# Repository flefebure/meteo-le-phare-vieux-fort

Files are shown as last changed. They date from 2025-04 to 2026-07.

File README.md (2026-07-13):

# La balise météo du phare de Vieux-Fort en Guadeloupe

Nous sommes André ("l'électricien"), Yves ("le chef de projet"), Franck ("le data engineer") et Noël (le Potomitan du phare), quatre pratiquants de wingfoil réguliers (pas des plus jeunes) du spot. Vous nous avez sans doute croisés si vous fréquentez le lieu pour naviguer, plonger, sauter, bronzer, pique-niquer... dans cet endroit magnifique.

Avec le support de Thierry pour la partie "électronique", nous sommes à l'origine de l'installation de ce matériel qui a été mis en place avec une approche "DIY" et communautaire.

Vous trouverez ici le processus d'installation de cette borne, afin que vous puissiez la répliquer. Nous vous y encourageons.

## Choix des technologies

### Le matériel

La borne est destinée a être installée sur la galerie au sommet du phare de Vieux-Fort. Ainsi il est primordial qu'elle soit la plus robuste et la plus autonome possible. En effet toute intervention nécessitera une synchronisation avec le personnel des phares & balises. Par ailleurs, la borne ne pourra pas puiser son énergie au niveau des installations électriques du phare, il faut donc qu'elle soit autonome en énergie.

Basiquement, nous devions arbitrer entre 2 technologies :

1. Un montage communiquant sur un réseau haut-débit (GSM 4G/5G)
   * Avantages : Réseau autonome. Transmission des données à haute fréquence. Possibilité d'équiper la borne d'une caméra.
   * Inconvénients : technologie gourmande en énergie. Nécessité de mettre en place une recharge solaire (relativement) conséquente.
2. Un montage communiquant sur un réseau bas-débit (LORA ou SigFOX)
   * Avantages : Très économe en énergie, autonomie théorique de plusieurs années.
   * Inconvénients : Nécessité d'intégrer un point d'accès à Internet. Webcam pas envisageable.

Le point de l'énergie étant prédominant, c'est sur une installation Lora que le choix s'est porté. C'est Yves, qui vit à quelques centaines de mètres à vol d'oiseau qui hébergera la passerelle Internet.

### Le logiciel

Les choix suivants s'offraient a nous :

1. Mettre en place une stack "Internet Of Things" complète avec un broker MQTT et un site web autonome abonné à ce broker et chargé d'exposer les données météo
2. Centraliser le traitement des données au niveau de la gateway Lora et s'appuyer sur un service à la "WindGuru" pour présenter les données.

Par souci de simplicité, c'est l'option 2. qui a été choisie. Néanmoins, afin d'assurer une redondance, la borne sera intégrée à 2 services tiers : WindGuru et OpenWindMap

## Raccordement des matériels

La borne se compose des éléments suivants :

| Item | Lien | Prix | Doc |
| :---: | :---: | :---: | :---: |
| Anémomètre Davis 6410 | [Fiche produit](https://github.com/flefebure/meteo-le-phare-vieux-fort/blob/0f8d7a7ca1cc759bb87fbd7ad5027cff3bb662dc/medias/6410_An%C3%A9mom%C3%A8tre_FICHE%20PRODUIT_FR_DAVIS-1.pdf) | ~245€ | [Manuel](https://www.meteo-shopping.com/fr/capteurs/109-anemometre-girouette-vantage-pro.html) |
| Boitier émetteur Dragino SN50v3-LS | [Fiche produit](https://www.dragino.com/products/lora-lorawan-end-node/item/260-sn50v3-lb-ls.html) | ~60€ | [Manuel](https://wiki-old.dragino.com/xwiki/bin/view/Main/User%20Manual%20for%20LoRaWAN%20End%20Nodes/SN50v3-LB/) |
| Gateway Lora Dragino LPS8v2 | [Fiche produit](https://www.dragino.com/products/lora-lorawan-gateway/item/228-lps8v2.html) | 190 à 260€ suivant model | [Manuel](https://wiki-old.dragino.com/xwiki/bin/view/Main/User%20Manual%20for%20All%20Gateway%20models/HP0C/) |
| Capteur de température DS18B20 | [Fiche produit](https://www.amazon.fr/DS18B20/s?k=DS18B20) | ~3 € | [Datasheet](https://www.analog.com/media/en/technical-documentation/data-sheets/ds18b20.pdf) |
| Divers : Mât etc. | ? | ??€ | ?? |

Le boitier émetteur Dragino SN50v3-LB/LS existe en 2 versions :
*	SN50v3-LB qui fonctionne sur pile Li/SOCl2 de 8500mAh d'une durée d’environ 3-5 ans (suivant consommation des capteurs)
*	SN50v3-LS qui fonctionne sur panneau solaire + batterie lithium ion

La version SN50v3-LS a été choisi car elle évite la maintenance d’un changement de batterie.

### Raccordement des éléments

La girouette/anémomètre Davis est câblée avec un connecteur RJ11 male. Le capteur de température est câblé avec une fiche Dupont 3pin male.

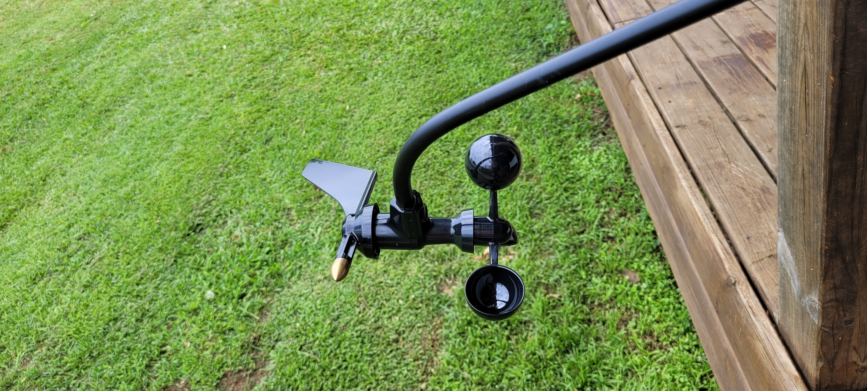
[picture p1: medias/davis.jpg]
girouette/anémomètre Davis

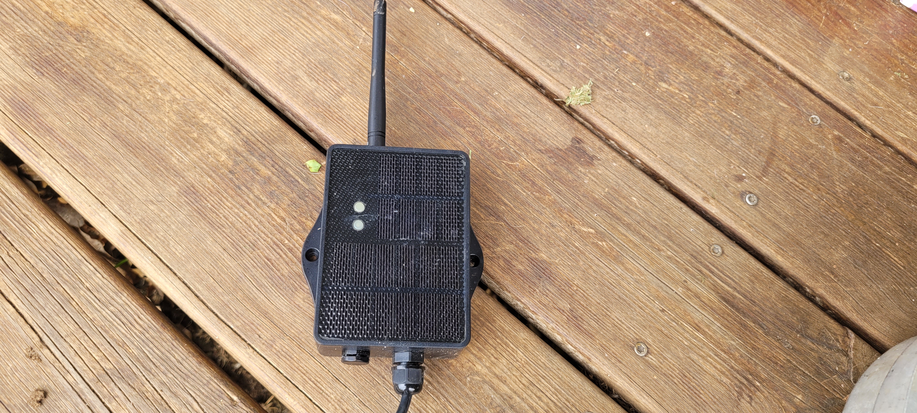
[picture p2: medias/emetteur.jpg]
emetteur Dragino

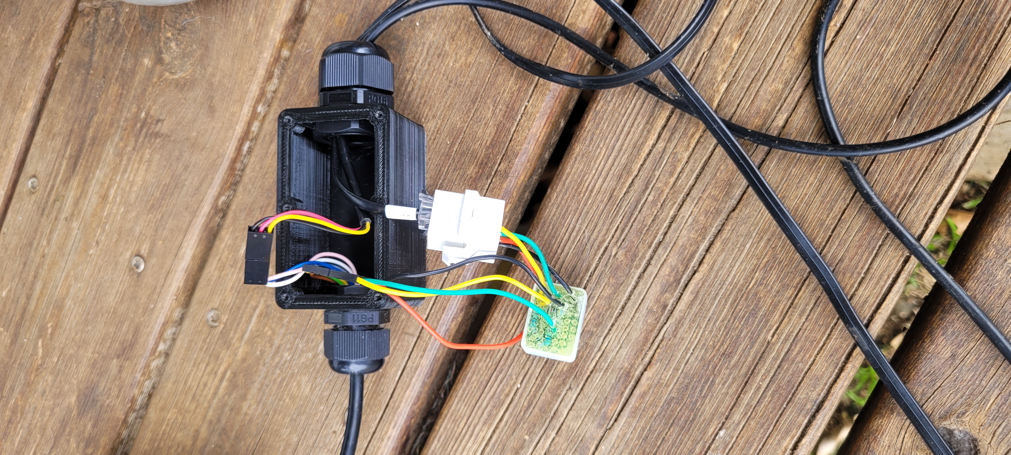
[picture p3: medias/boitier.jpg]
Cablage et boitier imprimé en 3D


La tension de sortie de la girouette varie entre 0V et la tension d'alimentation du boitier émetteur Vdd soit 3.3V. La tension d'entrée du convertisseur ADC de l'émetteur doit être comprise entre 0.1V et 1.1V. Il faut donc mettre en œuvre un pont de résistances afin d'adapter le voltage

Principe :

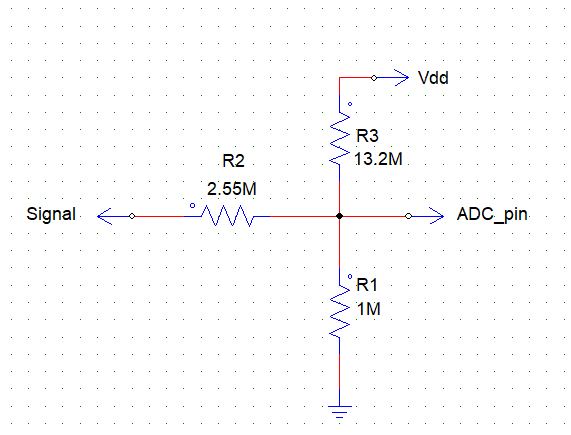
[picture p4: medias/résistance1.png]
Adaptation du voltage


Schema de branchement :

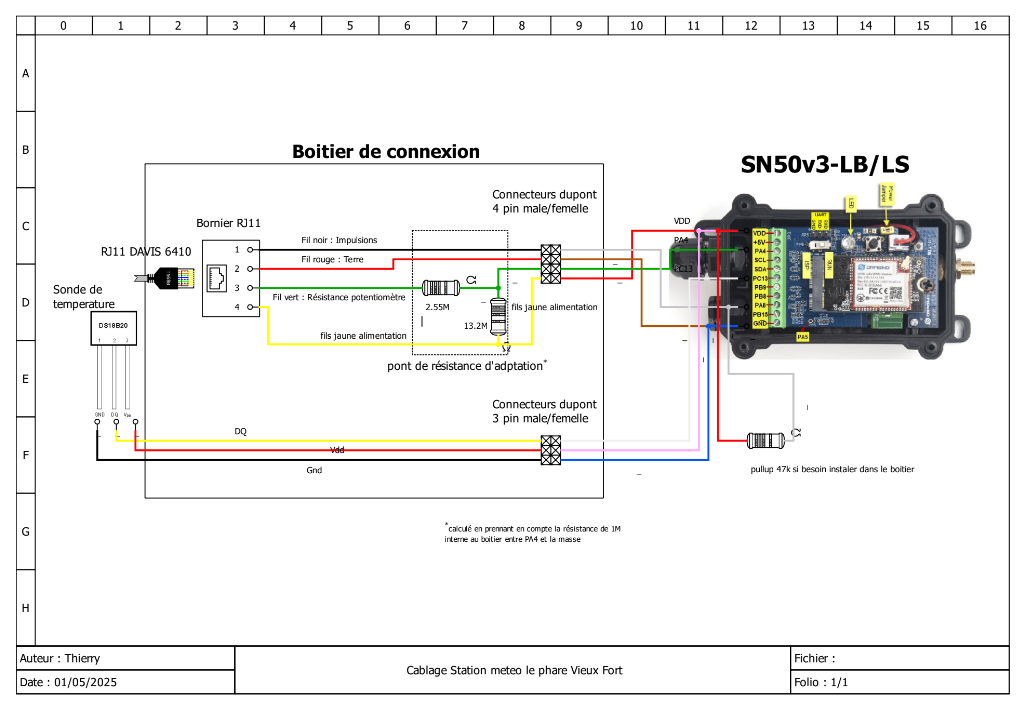
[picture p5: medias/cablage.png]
Schema de branchement


NB:

* Le circuit des résistances est pris dans de la résine coulée dans un petit boitier
* L'ensemble des connections est contenu dans un boitier imprimé en 3D avec du PETG comportant 2 passe-câble avec presse-étoupes en plastique étanche PG11 et PG13.5. Les presse-étoupes ont un diamètre interne de 11 mm et 13.5 mm pour pouvoir insérer les câbles avec leur connecteur. Enfin des bagues d’étanchéité sont imprimée en TPU pour adapter le diamètre des câbles au presse étoupe. Les différent fichiers STL sont disponible ci-dessous :
  * [Bague étanche diamètre 10](medias/bague%20etanche%20d10.5_d5mm.stl)
  * [Bague étanche diamètre 13](medias/bague%20etanche%20d13.5_d4mm.stl)
  * [Haut du boitier](medias/boitier%20connexion%20haut.stl)
  * [Bas du boitier](medias/boitier%20connexion%20bas.stl)

La sonde de température est la classique DS18B20:

 * 
   
 celle-ci est installé dans un écran radiatif qui est une adaptation/mise à l'échelle de [Radiation Shield For Weather Station Temperature/Humidity](https://www.thingiverse.com/thing:1067700):
 
  

L'écran radiatif est imprimé en PETG blanc. Les différents fichiers STL sont disponible ci-dessous :
  * [Support écran](medias/Rad_Shd_Vert_mount_60%25.stl)
  * [porte sonde](medias/Rad_Shd_Porte_sonde_60%25.stl)
  * [Aillete intermédiare x4](medias/Rad_Shd_ailette_60%25.stl)
  * [Ailette supérieur](medias/Rad_Shd_ailette_superieur_60%25.stl)
  * [écran radiatif complet monté](medias/Rad_Shd_Vert_mount_complet_V3_60%25.stl)

L'ensemble des pieces sont relier/empilé entre elle par 3 vis d3mm*60mm qui se visse dans l'ailette supérieur (tarauder les trous avant montage)

### Paramétrage de l'émetteur

Le boitier émetteur Dragino SN50v3-LB/LS est un boitier multi usage qui demande à être configuré en fonction de l’application et des capteurs qui seront connecté dessus. La documentation propose différent mode : [Mode boitier](https://wiki-old.dragino.com/xwiki/bin/view/Main/User%20Manual%20for%20LoRaWAN%20End%20Nodes/SN50v3-LB/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)

Dans notre cas nous allons utiliser le mode comptage : Mode 6, car nous avons à compter les tours de rotation de l’anémomètre, mesurer le potentiomètre de la girouette et mesurer la température.
Le boitier SN50v3-LB/LS prend en charge les méthodes de configuration suivante :
* Commande AT via connexion Bluetooth (recommandée): [BLE Configure Instruction](https://wiki-old.dragino.com/xwiki/bin/view/Main/BLE%20Bluetooth%20Remote%20Configure/).
* Commande AT via connexion UART voir : [UART Connection](https://wiki-old.dragino.com/xwiki/bin/view/Main/UART%20Access%20for%20LoRa%20ST%20v4%20base%20model/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).
* Par liaison descendante LoRaWAN.  Voir instruction : [IoT LoRaWAN Server section](https://wiki-old.dragino.com/xwiki/bin/view/Main/).

La méthode « Commande AT via connexion Bluetooth » a été utilisé :

Après installation sur un téléphone Android de l'utilitaire dragino "Devices.Toll" les commandes AT nécessaire à la configuration souhaitée ont été envoyé :

* Commande de passage en mode 6 : AT+MOD=6
* Définition de la période de transmission en ms : AT+TDC=30000 (30000ms= 30s)

### Configuration du réseau Lorawann de la passerelle utilisé par l'émetteur

La passerelle permet de configurer l'accés à un réseau Lorawann comme par exemple [The Things Network V3](https://www.thethingsnetwork.org/) ou d'utiliser le réseau lorawan local à la passerelle. Dans notre cas nous avons utilisé le réseau local "Chirpstack". les informations de configuration sont à retrouver dans Manuel utilisateur de la Gateway Lora Dragino LPS8v2 : [Manuel](https://wiki-old.dragino.com/xwiki/bin/view/Main/User%20Manual%20for%20All%20Gateway%20models/HP0C/)

## Mise en œuvre logicielle

### administration passerelle

Une fois la passerelle Lora branchée sur un routeur internet, celui-ci lui affecte une IP DHCP, par exemple 192.168.1.20
Un acces à http://192.168.1.20 permet d'afficher l'interface d'administration de la passerelle
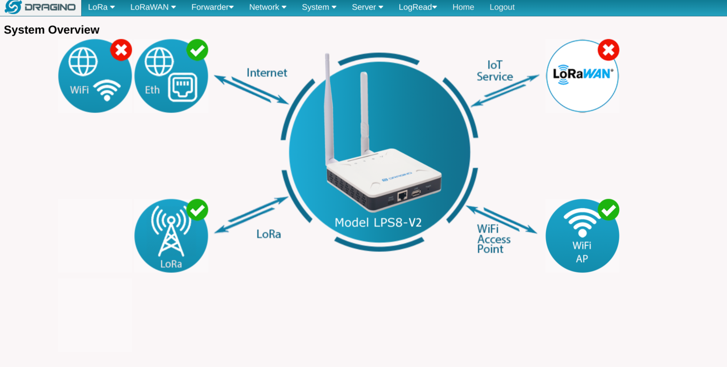
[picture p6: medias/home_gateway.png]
acceuil gateway


Cette interface est surtout utilse pour vérifier que la paserelle est bien connectée à l'émetteur et peut accéder à Internet. La majeure partie des configurations s'effectue via l'utilitaire "Chirpstack" qui est disponible a l'adresse http://192.168.1.20:8080

### Chirpstack

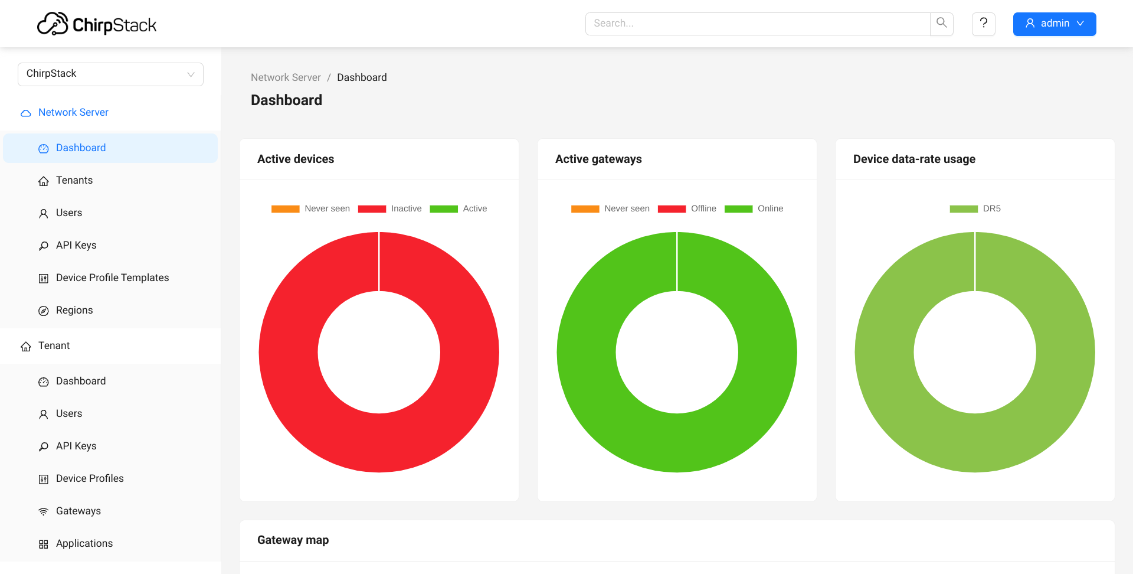
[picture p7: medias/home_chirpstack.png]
acceuil Chirpstack


La premiere tâche est de créer un template pour l'émetteur 
Voici notre configuration :

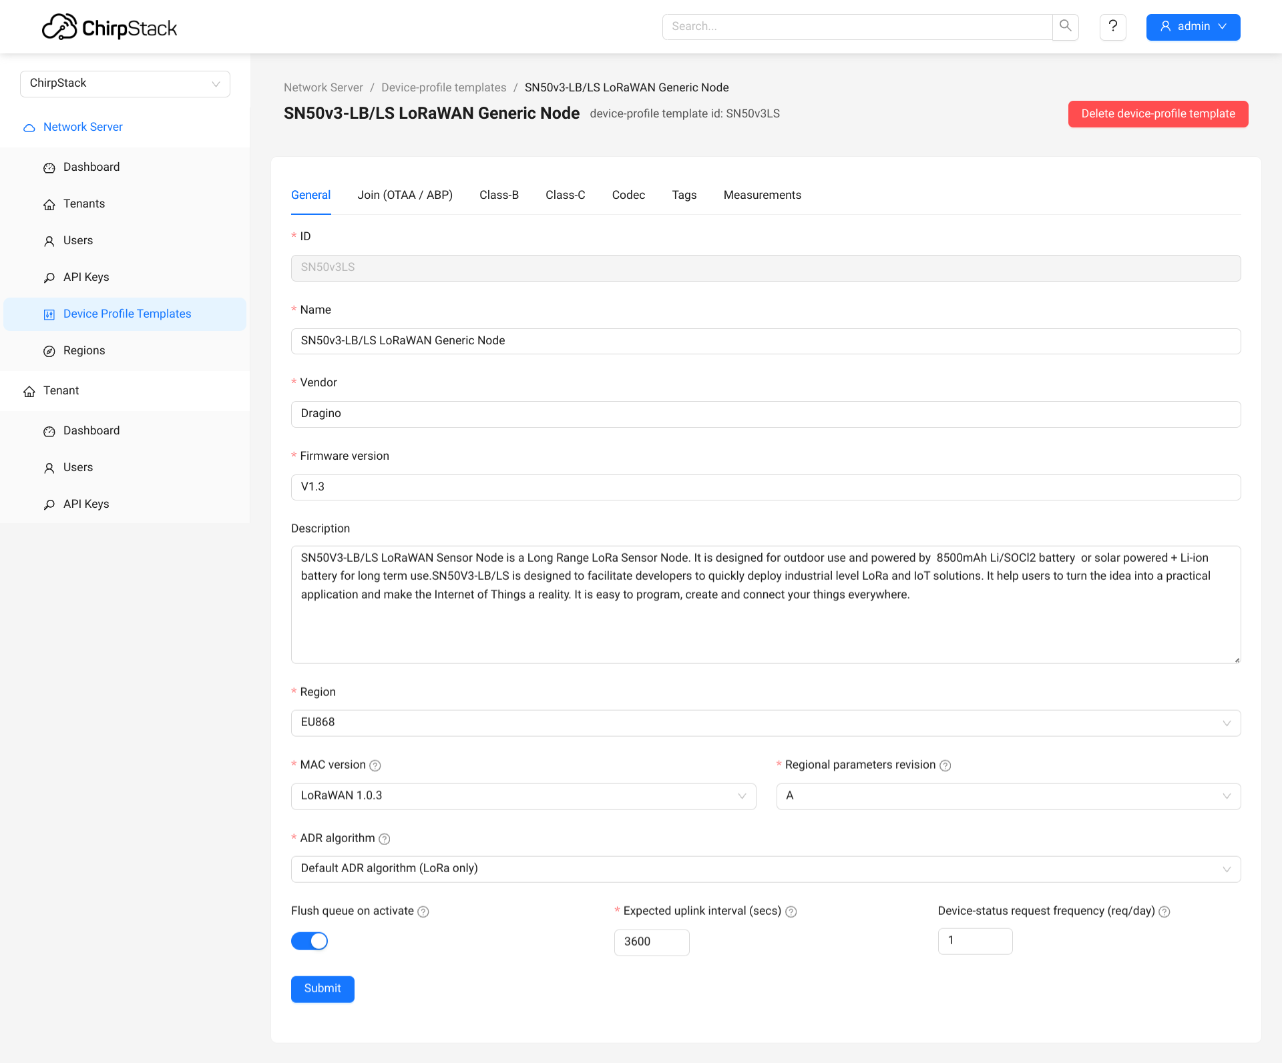
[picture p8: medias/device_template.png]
Template device


Il faut ensuite définir un template, en effet l'émetteur Lora envoie ses données sous forme de trames hexadécimales, le codec va permettre de convertir la charge utile de ces trames en informations utilisables, par exemple la température ou le nombre de rotations de l'anémomètre. 
Le wiki de Dragino vous propose un Codec à utiliser

[Codec](https://github.com/dragino/dragino-end-node-decoder/blob/main/SN50_v3-LB/SN50_v3-LB_ChirpstackV4_decode.txt)

Collez simplement le contenu de ce fichier dans la partie Codec du template

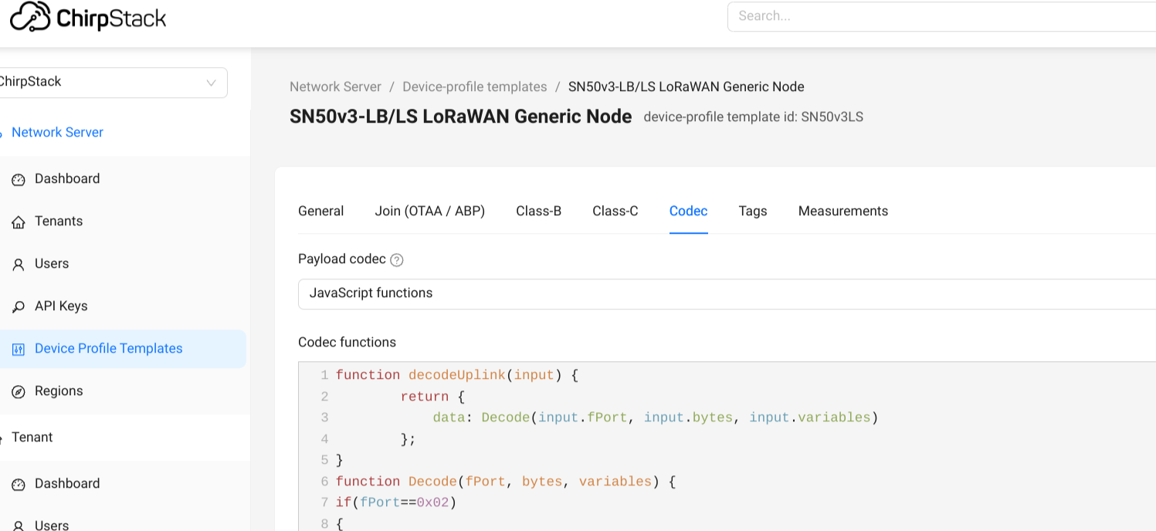
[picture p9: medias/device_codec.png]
Template device


Définissez ensuite une "Gateway". Vous aurez a renseigner le code EUI64 de l'émetteur qui figure sur son étiquette

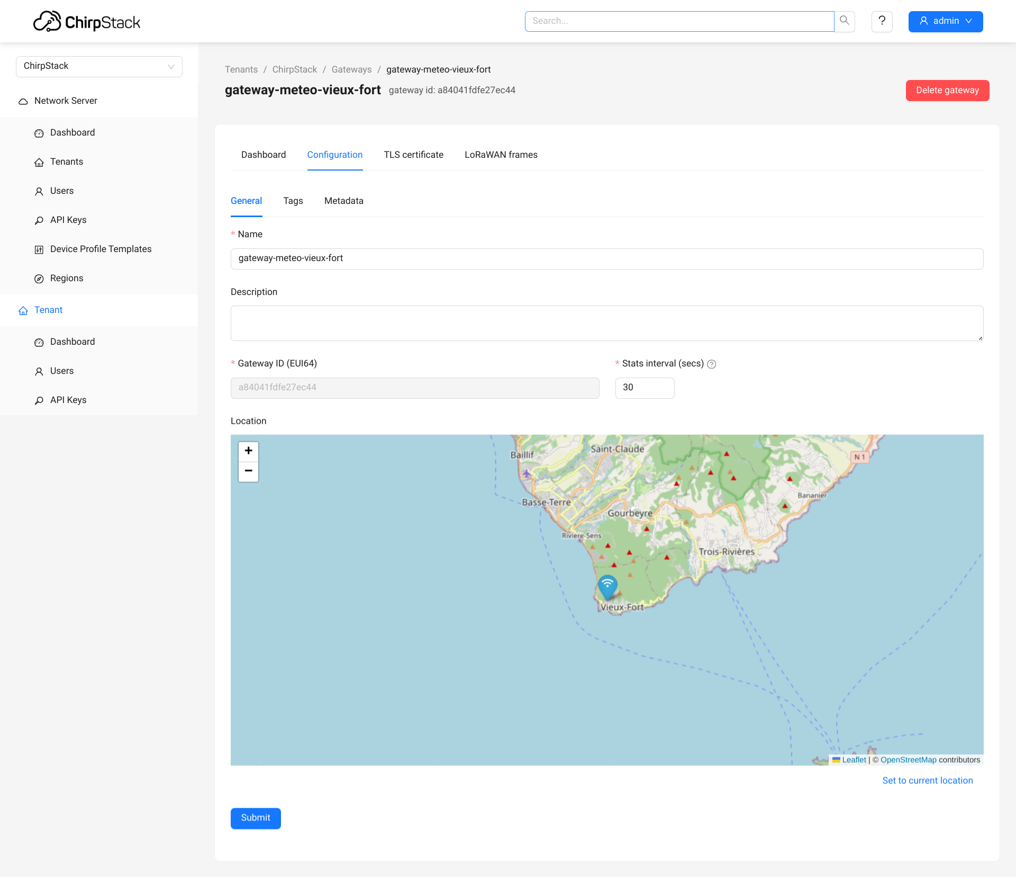
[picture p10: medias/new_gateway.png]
New gateway


Enfin vous aurez a définir une "application", qui fait le lien entre la gateway et le device

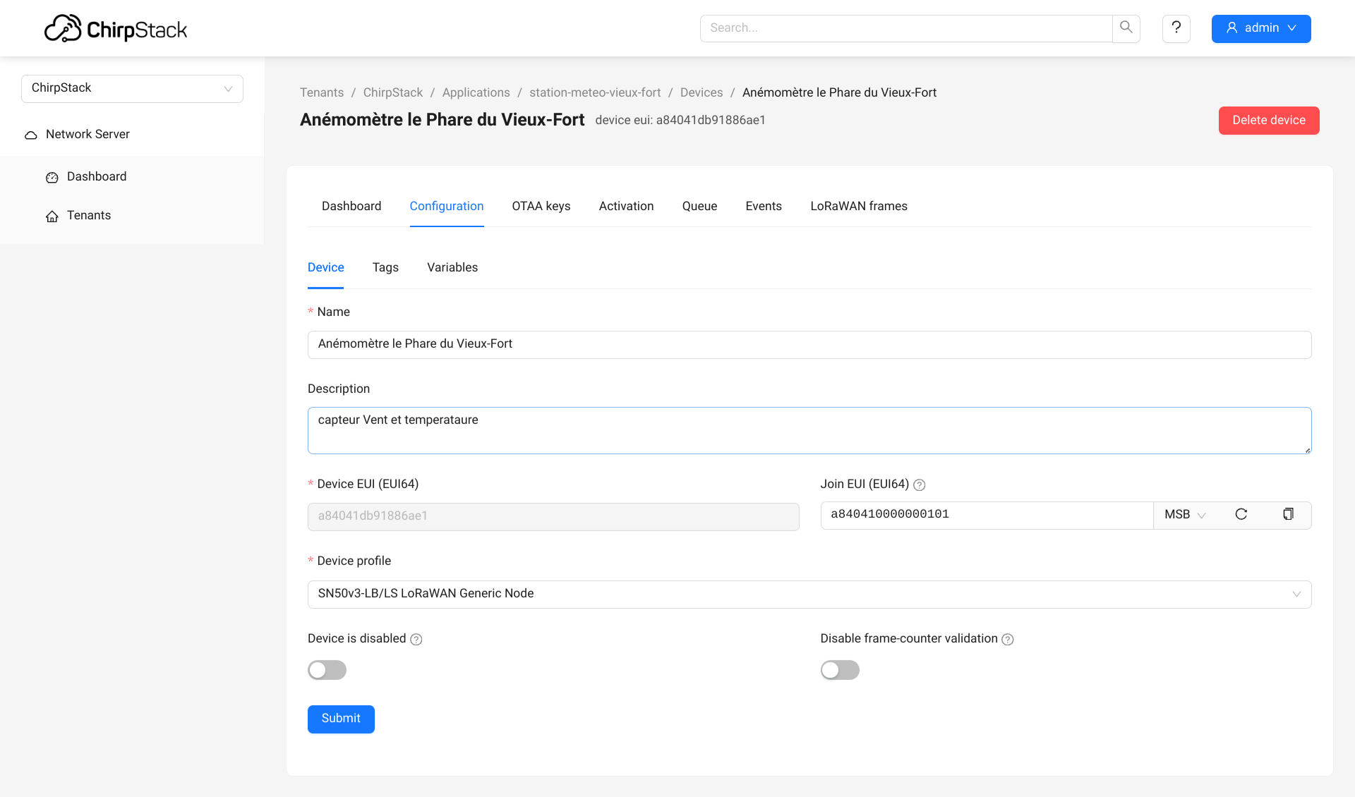
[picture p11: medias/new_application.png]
New app


A ce stade, vous devez pouvoir visualiser les événements décodés qui proviennent de l'émetteur

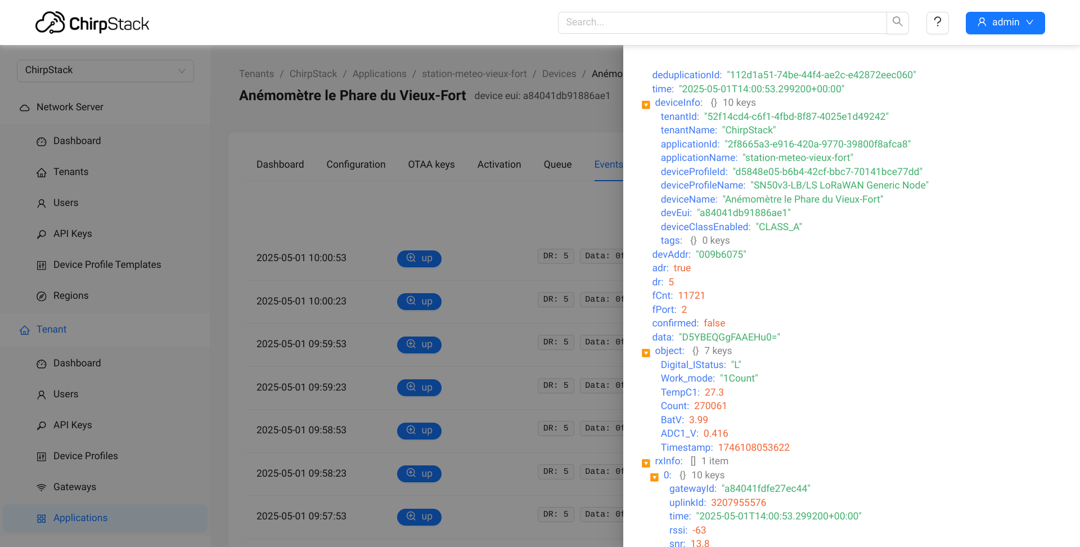
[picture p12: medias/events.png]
Evénements


Pour la suite de la configuration, il était prévu de sauvegarder les événements dans une base locale pour ensuite les traiter et les transmettre aux services tiers (Windguru) et pour cela j'ai essayé de mettre en œuvre une "integration" de type "InfluxDB"

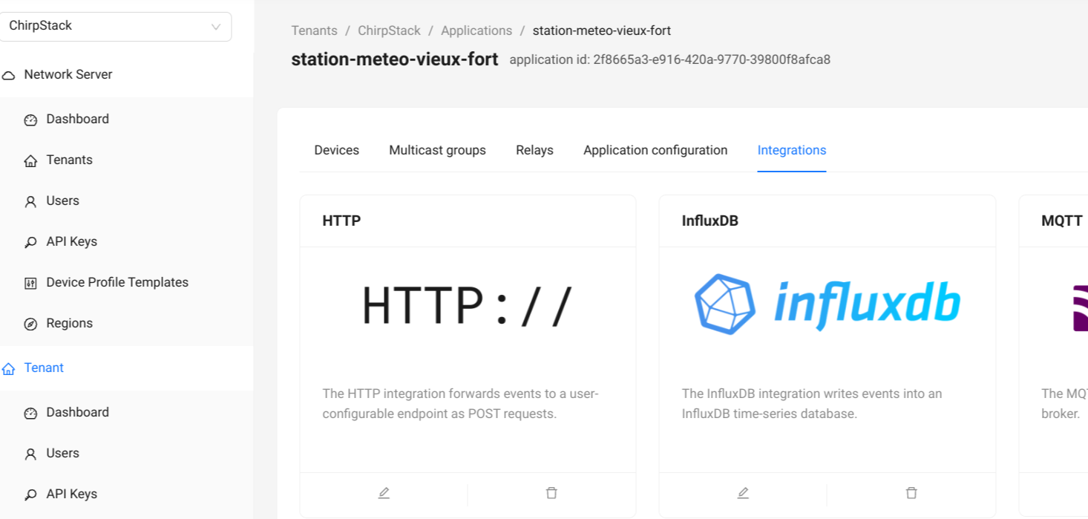
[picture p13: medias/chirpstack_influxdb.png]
Chirpstack to Influx


Néanmoins, je ne suis pas parvenu à faire fonctionner ce connecteur. La mise en œuvre a par la suite été centralisée dans un 3e outil : Node-Red

### InfluxDB

La base conseillée par Dragino n'est pas installée par défaut. Pour l'installer, connectez-vous par SSH a l'IP de la passerelle puis exécutez les commandes suivantes :

```
curl https://repos.influxdata.com/influxdata-archive_compat.key | gpg --dearmor | sudo tee /usr/share/keyrings/influxdb-archive-keyring.gpg >/dev/null
echo "deb [signed-by=/usr/share/keyrings/influxdb-archive-keyring.gpg] https://repos.influxdata.com/debian $(lsb_release -cs) stable" | sudo tee /etc/apt/sources.list.d/influxdb.list
apt update && apt install influxdb
systemclt enable influxdb
systemctl start influxdb
```

Vérifiez ensuite que la base est demarrée avec la commande "systemctl status influxdb"

## Node Red

Node Red est un outil de programmation visuelle (low-code) embarqué dans la passerelle Dragino. Il est disponible à l'adresse http://192.168.1.20:1880

Les mesures des capteurs sont disponibles sur la queue MQTT locale à la passerelle Dragino

Dans RedNode nous allons traiter 2 flux de données :

* Un premier "stream" qui stocke toutes les mesures reçues sur la queue MQTT dans la base InfluxDB
* Un deuxième "stream" qui s'exécute toutes les minutes et qui traite les mesures reçues pendant les 5 dernières minutes afin de les transformer puis de les transmettre a OpenWindMap et WindGuru

Voici comment se présente les 2 streams dans Node Red :

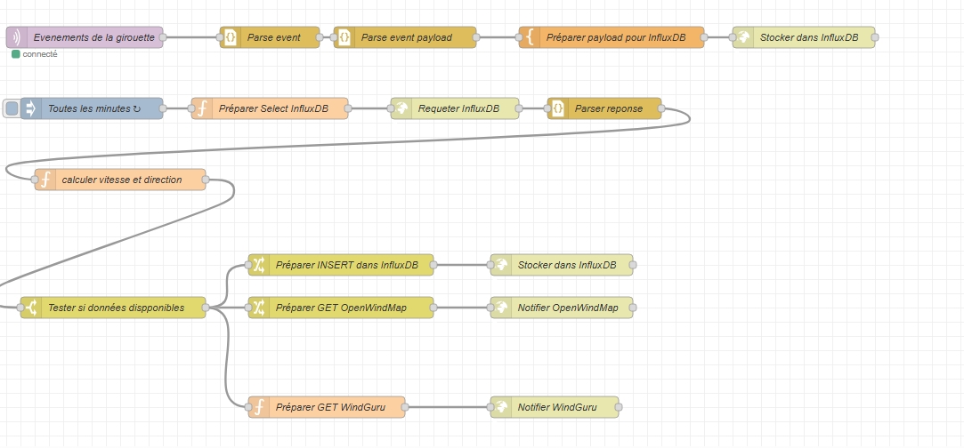
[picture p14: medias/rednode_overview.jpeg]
NodeRed overview


### Stockage des événements

Le flux démarre par un noeud MQTT-IN. Le "topic" est "application/+/device/+/event/+"

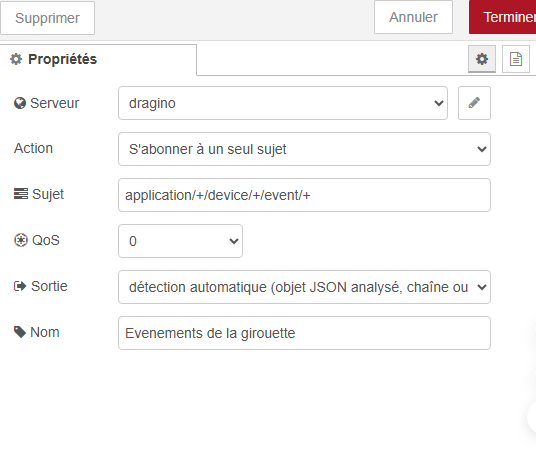
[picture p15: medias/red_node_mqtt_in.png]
MQTT IN


Le format de l'événement est assez particulier. C'est une chaine Json encapsulée dans un autre objet Json. Il faut donc le décoder en 2 étapes. C'est ce qui explique les 2 noeuds "parse event" en cascade

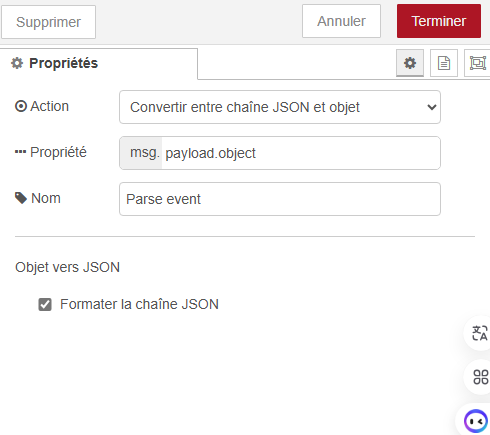
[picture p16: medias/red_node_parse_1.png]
parse event etape 1
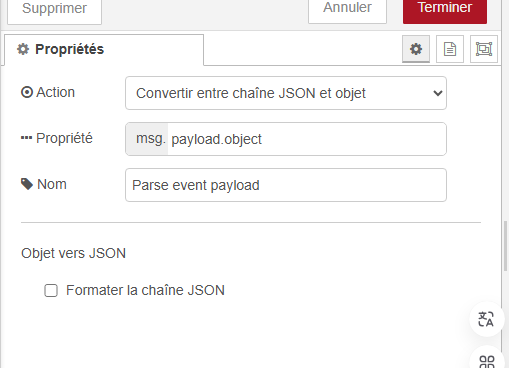
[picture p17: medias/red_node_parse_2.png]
parse event etape 2
  

On prépare alors l'insertion dans InfluxDB, via son API HTTP

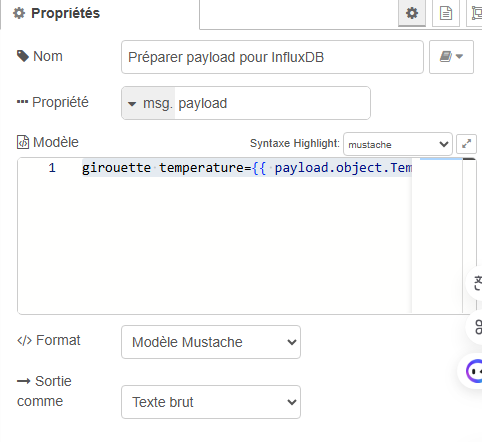
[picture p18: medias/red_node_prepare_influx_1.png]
Prepare Influx insert


```
girouette temperature={{ payload.object.TempC1 }},batterie={{ payload.object.BatV }},rotations={{ payload.object.Count }},voltage={{ payload.object.ADC1_V }} {{ payload.object.Timestamp }}
```

Enfin on insere l'événement dans InfluxDB

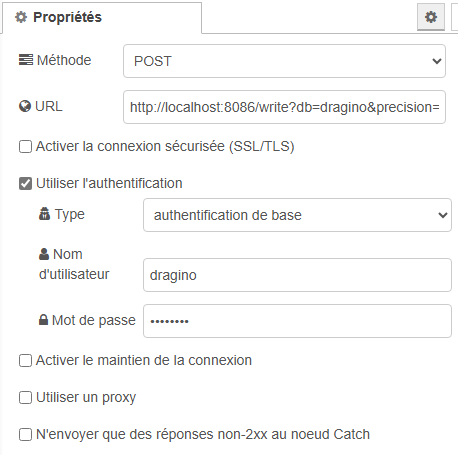
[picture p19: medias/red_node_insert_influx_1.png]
Insertion Influx


### Traitement des événements

Le premier nœud est un scheduler Node Red qui diffuse un événement toutes les minutes.

Nous allons enrichir cet événement avec la liste des mesures recueillies pendant les 5 dernières minutes

TODO : détailler requete et reponse InfluxDB

Les mesures sont disponibles, nous pouvons maintenant calculer les métriques finales selon ces règles :

* Les vitesses en km/h seront données par la formule suivante :  V = P*(2.25*1.60934/T) avec P le nombre de rotations entre 2 points de mesure et T le temps en secondes entre ces 2 mesures (formule adaptée de la documentation DAVIS 6410)
* La vitesse moyenne est obtenue en prenant en compte les 2 points de mesure les plus éloignés sur la période de 5 minutes.
* Les vitesses min et max sont obtenues entre 2 points de mesures consécutifs  (éloignés de 30 secondes) sur la période de 5 minutes.
* La direction du vent en degrés par rapport au nord est donnée par la formule suivante : y = modulo(395,1932806 *x - 59,62030662 + Cal, 360), ou x est la mesure en volts du boitier (entre 0.1 et 1V environ) et Cal est la direction du support girouette par rapport au nord (Si on pointe le support girouette vers le nord alors Cal = 0 si tu pointe l’EST Cal = 90, le sud Cal = 180 et l’ouest  Cal = 270).
la formule donnant la direction du vent en degrés a été obtenue en effectuant une calibration de la girouette connectée au boitier : pour différente position de la girouette on mesure la tension du potentiomètre et la valeur renvoyée par l’ADC du boitier puis on passe une droite de régression a*x+b. si un autre modèle de girouette est  utilisé  ou si un  autre pont de résistance est mis en œuvre, la calibration est à refaire

Le code figurant dans le noeud fonction "calculer vitesse et direction" est donc :

```
var values = msg.payload.results[0].series[0].values
var rotations_reset = 0
var sum_voltage = 0

var payload = {}
payload.min_time = 0
payload.start_rotations = 0
payload.end_rotations = 0
payload.vitesse_min_kmh = 1000000
payload.vitesse_max_kmh = 0

var voltage = 0
payload.count = values.length
msg.payload = payload
if (payload.count < 2)
    return msg;
for (let value of values)  {
    if (payload.min_time == 0) payload.min_time = value[0]
    if (payload.start_rotations == 0) payload.start_rotations = value[3]
    payload.temperature = value[1]
    payload.batterie = value[2]
    sum_voltage = sum_voltage + value[4]
    if (value[3] < payload.end_rotations) 
        rotations_reset = payload.end_rotations
    
    var pulse = value[3] + rotations_reset - payload.end_rotations
    if (payload.max_time > 0) {
        var vitesse_inst_kmh = pulse * 2.25 *  1.60934 * 1000 / (value[0] - payload.max_time)
        if (vitesse_inst_kmh > payload.vitesse_max_kmh)
            payload.vitesse_max_kmh = vitesse_inst_kmh 
        if (vitesse_inst_kmh < payload.vitesse_min_kmh)
            payload.vitesse_min_kmh = vitesse_inst_kmh
    }
    
    payload.end_rotations = value[3] + rotations_reset
    payload.max_time = value[0]
}
// calcul de la direction du vent
var avg_angle = 0
if (payload.count > 0)
    voltage = sum_voltage / payload.count
payload.angle = (395.1932806 * voltage - 59.62030662 + 180) % 360
// calcul de la vitesse
payload.secondes = (payload.max_time - payload.min_time) /1000
payload.pulse = payload.end_rotations - payload.start_rotations
payload.vitesse_kmh = payload.pulse * 2.25 *  1.60934 / payload.secondes 
payload.vitesse_ms = payload.vitesse_kmh / 3.6
payload.vitesse_max_ms = payload.vitesse_max_kmh / 3.6
payload.vitesse_min_ms = payload.vitesse_min_kmh / 3.6
return msg;
```

Un test, utilisant un noeud redNode de type "switch" est mis en place pour arrêter le traitement si on n'a pas trouvé au moins 2 mesures sur la période de 5 minutes

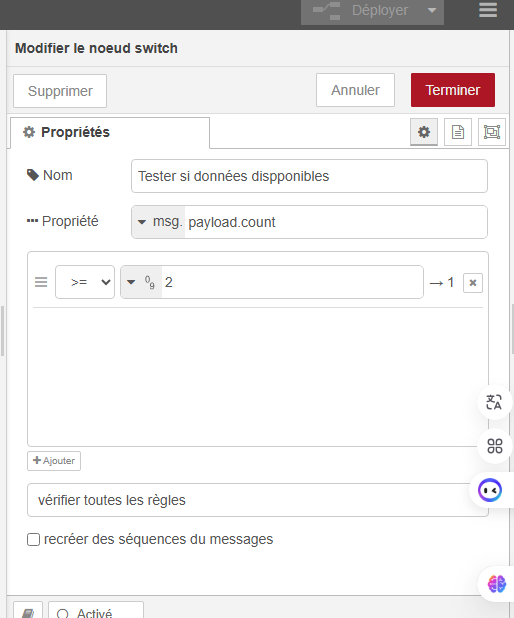
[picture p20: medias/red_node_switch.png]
Test 2 mesures


On prépare l'appel a l'API OpenWindMap

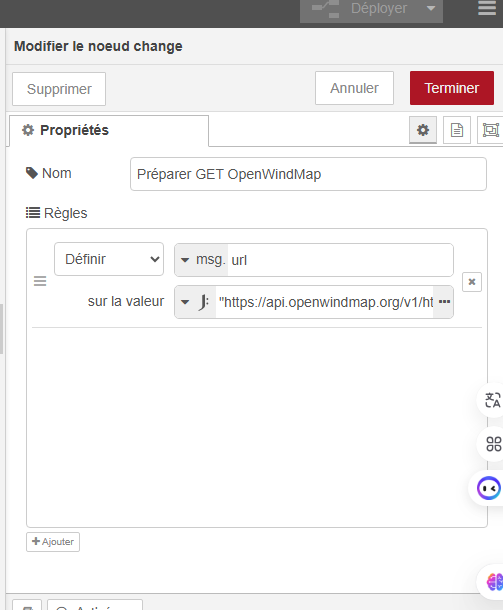
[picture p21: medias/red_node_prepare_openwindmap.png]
prepare openwindmap


```
"https://api.openwindmap.org/v1/http-receive/1227?key=**************&avg=" & payload.vitesse_kmh & "&heading=" & payload.angle & "&voltage=" & payload.batterie & "&temperature=" & payload.temperature & "&date=" & payload.max_time & "&min=" & payload.vitesse_min_kmh & "&max=" & payload.vitesse_max_kmh
```

La préparation de l'appel a l'API Windguru est un peu plus complexe car on doit calculer un MD5. Une fonction autonome permettant de calculer des MD5 est embarquée dans notre code.

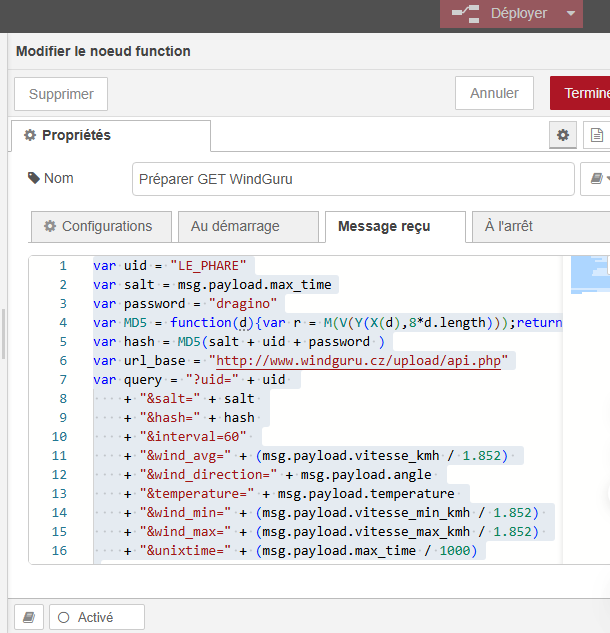
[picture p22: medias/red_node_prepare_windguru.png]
prepare windguru


```
var uid = "LE_PHARE"
var salt = msg.payload.max_time
var password = "*******"
var MD5 = function(d){var r = M(V(Y(X(d),8*d.length)));return r.toLowerCase()};function M(d){for(var _,m="0123456789ABCDEF",f="",r=0;r<d.length;r++)_=d.charCodeAt(r),f+=m.charAt(_>>>4&15)+m.charAt(15&_);return f}function X(d){for(var _=Array(d.length>>2),m=0;m<_.length;m++)_[m]=0;for(m=0;m<8*d.length;m+=8)_[m>>5]|=(255&d.charCodeAt(m/8))<<m%32;return _}function V(d){for(var _="",m=0;m<32*d.length;m+=8)_+=String.fromCharCode(d[m>>5]>>>m%32&255);return _}function Y(d,_){d[_>>5]|=128<<_%32,d[14+(_+64>>>9<<4)]=_;for(var m=1732584193,f=-271733879,r=-1732584194,i=271733878,n=0;n<d.length;n+=16){var h=m,t=f,g=r,e=i;f=md5_ii(f=md5_ii(f=md5_ii(f=md5_ii(f=md5_hh(f=md5_hh(f=md5_hh(f=md5_hh(f=md5_gg(f=md5_gg(f=md5_gg(f=md5_gg(f=md5_ff(f=md5_ff(f=md5_ff(f=md5_ff(f,r=md5_ff(r,i=md5_ff(i,m=md5_ff(m,f,r,i,d[n+0],7,-680876936),f,r,d[n+1],12,-389564586),m,f,d[n+2],17,606105819),i,m,d[n+3],22,-1044525330),r=md5_ff(r,i=md5_ff(i,m=md5_ff(m,f,r,i,d[n+4],7,-176418897),f,r,d[n+5],12,1200080426),m,f,d[n+6],17,-1473231341),i,m,d[n+7],22,-45705983),r=md5_ff(r,i=md5_ff(i,m=md5_ff(m,f,r,i,d[n+8],7,1770035416),f,r,d[n+9],12,-1958414417),m,f,d[n+10],17,-42063),i,m,d[n+11],22,-1990404162),r=md5_ff(r,i=md5_ff(i,m=md5_ff(m,f,r,i,d[n+12],7,1804603682),f,r,d[n+13],12,-40341101),m,f,d[n+14],17,-1502002290),i,m,d[n+15],22,1236535329),r=md5_gg(r,i=md5_gg(i,m=md5_gg(m,f,r,i,d[n+1],5,-165796510),f,r,d[n+6],9,-1069501632),m,f,d[n+11],14,643717713),i,m,d[n+0],20,-373897302),r=md5_gg(r,i=md5_gg(i,m=md5_gg(m,f,r,i,d[n+5],5,-701558691),f,r,d[n+10],9,38016083),m,f,d[n+15],14,-660478335),i,m,d[n+4],20,-405537848),r=md5_gg(r,i=md5_gg(i,m=md5_gg(m,f,r,i,d[n+9],5,568446438),f,r,d[n+14],9,-1019803690),m,f,d[n+3],14,-187363961),i,m,d[n+8],20,1163531501),r=md5_gg(r,i=md5_gg(i,m=md5_gg(m,f,r,i,d[n+13],5,-1444681467),f,r,d[n+2],9,-51403784),m,f,d[n+7],14,1735328473),i,m,d[n+12],20,-1926607734),r=md5_hh(r,i=md5_hh(i,m=md5_hh(m,f,r,i,d[n+5],4,-378558),f,r,d[n+8],11,-2022574463),m,f,d[n+11],16,1839030562),i,m,d[n+14],23,-35309556),r=md5_hh(r,i=md5_hh(i,m=md5_hh(m,f,r,i,d[n+1],4,-1530992060),f,r,d[n+4],11,1272893353),m,f,d[n+7],16,-155497632),i,m,d[n+10],23,-1094730640),r=md5_hh(r,i=md5_hh(i,m=md5_hh(m,f,r,i,d[n+13],4,681279174),f,r,d[n+0],11,-358537222),m,f,d[n+3],16,-722521979),i,m,d[n+6],23,76029189),r=md5_hh(r,i=md5_hh(i,m=md5_hh(m,f,r,i,d[n+9],4,-640364487),f,r,d[n+12],11,-421815835),m,f,d[n+15],16,530742520),i,m,d[n+2],23,-995338651),r=md5_ii(r,i=md5_ii(i,m=md5_ii(m,f,r,i,d[n+0],6,-198630844),f,r,d[n+7],10,1126891415),m,f,d[n+14],15,-1416354905),i,m,d[n+5],21,-57434055),r=md5_ii(r,i=md5_ii(i,m=md5_ii(m,f,r,i,d[n+12],6,1700485571),f,r,d[n+3],10,-1894986606),m,f,d[n+10],15,-1051523),i,m,d[n+1],21,-2054922799),r=md5_ii(r,i=md5_ii(i,m=md5_ii(m,f,r,i,d[n+8],6,1873313359),f,r,d[n+15],10,-30611744),m,f,d[n+6],15,-1560198380),i,m,d[n+13],21,1309151649),r=md5_ii(r,i=md5_ii(i,m=md5_ii(m,f,r,i,d[n+4],6,-145523070),f,r,d[n+11],10,-1120210379),m,f,d[n+2],15,718787259),i,m,d[n+9],21,-343485551),m=safe_add(m,h),f=safe_add(f,t),r=safe_add(r,g),i=safe_add(i,e)}return Array(m,f,r,i)}function md5_cmn(d,_,m,f,r,i){return safe_add(bit_rol(safe_add(safe_add(_,d),safe_add(f,i)),r),m)}function md5_ff(d,_,m,f,r,i,n){return md5_cmn(_&m|~_&f,d,_,r,i,n)}function md5_gg(d,_,m,f,r,i,n){return md5_cmn(_&f|m&~f,d,_,r,i,n)}function md5_hh(d,_,m,f,r,i,n){return md5_cmn(_^m^f,d,_,r,i,n)}function md5_ii(d,_,m,f,r,i,n){return md5_cmn(m^(_|~f),d,_,r,i,n)}function safe_add(d,_){var m=(65535&d)+(65535&_);return(d>>16)+(_>>16)+(m>>16)<<16|65535&m}function bit_rol(d,_){return d<<_|d>>>32-_}
var hash = MD5(salt + uid + password )
var url_base = "http://www.windguru.cz/upload/api.php"
var query = "?uid=" + uid 
    + "&salt=" + salt 
    + "&hash=" + hash 
    + "&interval=60" 
    + "&wind_avg=" + (msg.payload.vitesse_kmh / 1.852) 
    + "&wind_direction=" + msg.payload.angle 
    + "&temperature=" + msg.payload.temperature 
    + "&wind_min=" + (msg.payload.vitesse_min_kmh / 1.852) 
    + "&wind_max=" + (msg.payload.vitesse_max_kmh / 1.852) 
    + "&unixtime=" + (msg.payload.max_time / 1000)

msg.url = url_base + query
return msg;
```
## Quelques images 

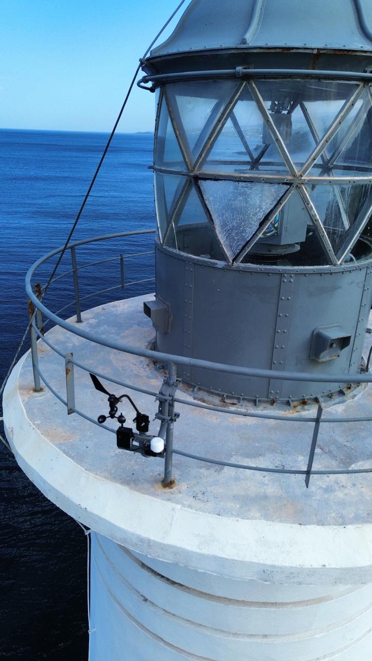
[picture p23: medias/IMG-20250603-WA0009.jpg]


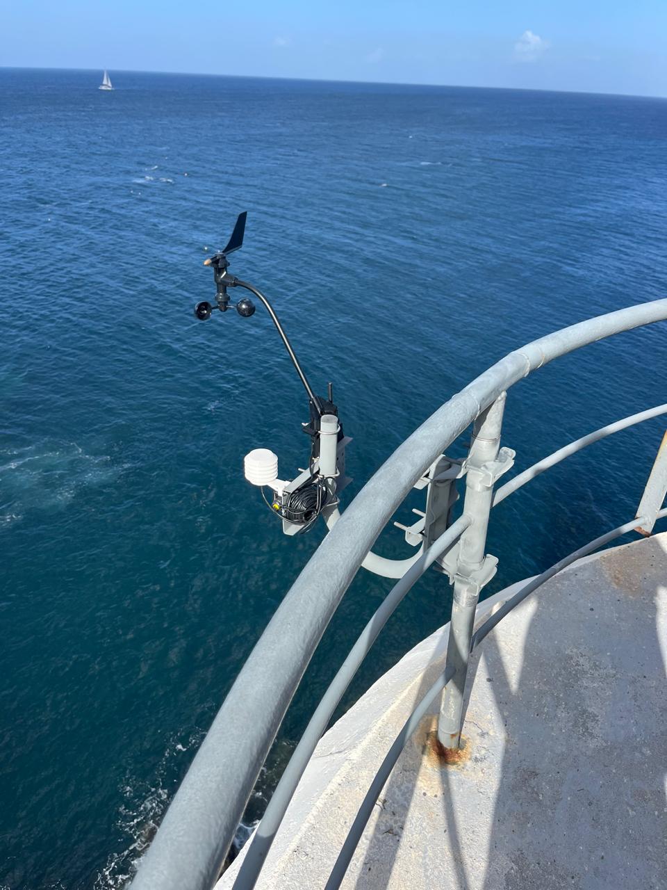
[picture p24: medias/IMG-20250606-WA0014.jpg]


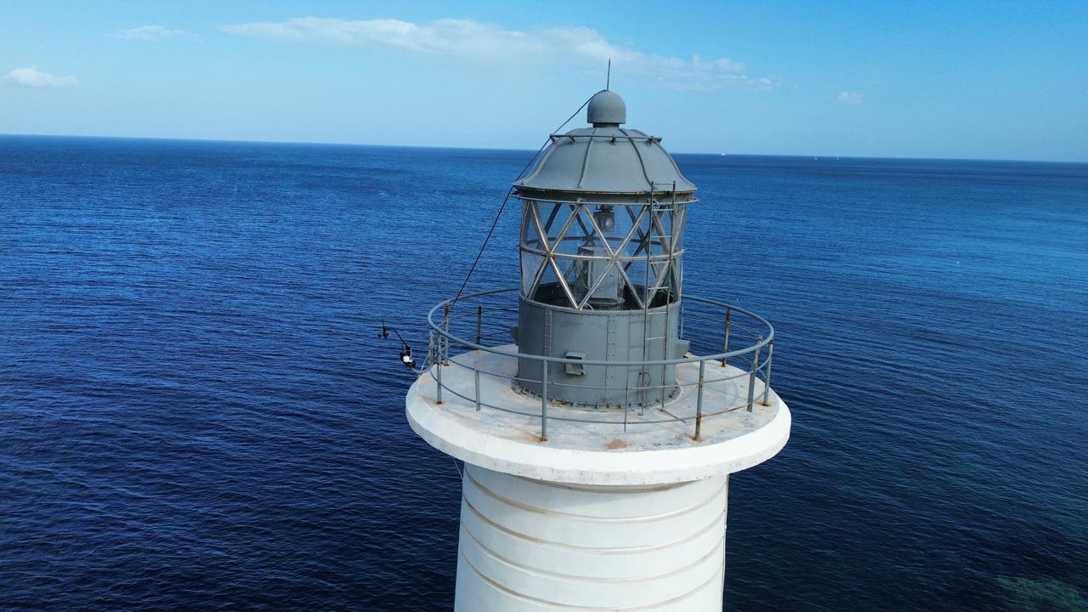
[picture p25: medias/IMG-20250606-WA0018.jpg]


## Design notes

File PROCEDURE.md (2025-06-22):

# Procédures diverses...

Les informations servant à établir les différentes procédures pratiques sont issue de la documentation Dragino et de son [wiki](https://wiki.dragino.com/xwiki/bin/view/Main/)

### Pour l'émetteur

Fiche produit de l’émetteur [SN50v3-LB/LS -- Waterproof Long Range Wireless LoRa Sensor Node](https://www.dragino.com/products/lora-lorawan-end-node/item/260-sn50v3-lb-ls.html)

Manuel utilisateur de l'émetteur [LoRaWAN SN50v3-LB/LS](https://wiki.dragino.com/xwiki/bin/view/Main/User%20Manual%20for%20LoRaWAN%20End%20Nodes/SN50v3-LB/)

Pour configurer le boitier SN50v3-LB/LS plusieurs méthodes de configuration sont disponible:

*	Commande AT via la connexion Bluetooth (recommandée): [BLE Configure Instruction](http://wiki.dragino.com/xwiki/bin/view/Main/BLE%20Bluetooth%20Remote%20Configure/).

*	Commande par Connection UART : [voir UART Connection](http://wiki.dragino.com/xwiki/bin/view/Main/UART%20Access%20for%20LoRa%20ST%20v4%20base%20model/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).

*	Par commande radio "LoRaWAN Downlink": [Instruction pour différentes plateformes sur le wiki dragino](http://wiki.dragino.com/xwiki/bin/view/Main/).

Les commandes générales permettent de configurer les paramètres généraux du système comme l'intervalle de temps de la liaison montante, le protocole radio LoRaWAN, etc. Elles sont communes à tous les boitiers Dragino qui prennent en charge la Stack LoRaWAN DLWS-005.
Ces commandes peuvent être trouvées sur le wiki à la section commande : [Commandes AT et commande Downlink](http://wiki.dragino.com/xwiki/bin/view/Main/End%20Device%20AT%20Commands%20and%20Downlink%20Command/)

Les commandes spécifiques au boitier SN50v3-LB/LS se retrouve dans le manuel utilisateur de l'émetteur à la section : [Commands special design for SN50v3-LB/LS](https://wiki.dragino.com/xwiki/bin/view/Main/User%20Manual%20for%20LoRaWAN%20End%20Nodes/SN50v3-LB/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)

### Pour la passerelle LoRaWAN

 Fiche produit de la Gateway Lora Dragino : [LPS8v2 -- Passerelle intérieure LoRaWAN](https://www.dragino.com/products/lora-lorawan-gateway/item/228-lps8v2.html)
 
 Manuel utilisateur de la Gateway Lora Dragino LPS8v2 : [Manuel](https://wiki.dragino.com/xwiki/bin/view/Main/User%20Manual%20for%20All%20Gateway%20models/HP0C/)

 Configuration du Serveur intégré par défaut  à la passerelle LoRaWAN LPS8-V2:
 * Serveur LoRaWAN pré-installé : [ChirpStack-V4ChirpStack-V4](https://www.chirpstack.io/docs/)
 * Application Server: [Node-Red](https://nodered.org/).
 * Configuration [Serveur intégré à la passerelle LoRaWAN LPS8-V2](https://wiki.dragino.com/xwiki/bin/view/Main/User%20Manual%20for%20All%20Gateway%20models/HP0C/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)

## Redémarrage à distance de l'émetteur
En cas de disfonctionnement du boitier SN50v3-LB/LS, il peut être nécessaire d'effectuer un reset du boitier. Cette commande de reset peut être envoyé avec les 3 méthodes de commande suivantes:

*	Commande AT via la connexion Bluetooth : [BLE Configure Instruction](http://wiki.dragino.com/xwiki/bin/view/Main/BLE%20Bluetooth%20Remote%20Configure/).

*	Commande par Connection UART : [voir UART Connection](http://wiki.dragino.com/xwiki/bin/view/Main/UART%20Access%20for%20LoRa%20ST%20v4%20base%20model/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).

*	Par commande radio "LoRaWAN Downlink": [Instruction pour différentes plateformes sur le wiki dragino](http://wiki.dragino.com/xwiki/bin/view/Main/).

Une fois installé sur site, dans notre cas, le boitier est inaccéssible et donc seul la dernière méthode par commande radio reste disponible.

Le principe d'utilisation des Commandes AT ou des Commandes Downlink sont données dans [le wiki ici](https://wiki.dragino.com/xwiki/bin/view/Main/End%20Device%20AT%20Commands%20and%20Downlink%20Command/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)

La description de la commande de reset est donnée dans [le wiki ici](https://wiki.dragino.com/xwiki/bin/view/Main/End%20Device%20AT%20Commands%20and%20Downlink%20Command/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) et décrite ci dessous:



L'envoie de cette commande sera faite à travers le serveur IoT LoRaWAN ChirpStack installé dans la passerelle. Dragino donne une [documentation d'utilisation ici](https://wiki.dragino.com/xwiki/bin/view/Main/Notes%20for%20ChirpStack/)

Pour un reset ponctuelle le plus simple est d'utiliser [l'interface utilisateur Web de ChirpStack](https://wiki.dragino.com/xwiki/bin/view/Main/Notes%20for%20ChirpStack/#H8.1ScheduleDownlinkviaWebUI) en ce connectant au serveur [Adresse_IP]:8080

Puis en allant dans: Tenants/ChirpStack/Applications/[Nom de l'application]/Devices/[Nom du Device] puis en cliquant sur l'onglet "Queue" on arrive sur la page de commande
remplir les champs comme sur l'image ci dessous

Capture d’écran 2025-06-22 141024

Enfin pousser la commande dans la queue d'envoie en cliquant sur "EnQueue". la commande sera envoyé après la prochaine réception d'un uplink par le serveur IoT LoRaWAN ChirpStack car c'est à ce momment que s'ouvre la fenettre de reception des message de commande par le boitier SN50v3-LB/LS.
On peux surveiller le bon déroulement de l'envoie de la commande et de son execution en allant dans le menu Events:

Capture d’écran 2025-06-22 150352

Ou l'on peut voir l'execution de l'envoie de la commande de reset suivi de la procédure de reconnection boitier SN50v3-LB/LS puis de l'envoie d'une trame de mesure.

En complément de cette methode manuel d'envoie de commande, il est possible d'utiliser le chirpStack et Node-Red au niveau du serveur local pour recevoir ou commander des messages: [voir exemple du wiki](https://wiki.dragino.com/xwiki/bin/view/Main/Notes%20for%20ChirpStack/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)

Enfin le [wiki d'installation et d'utilisation de Node-red](https://wiki.dragino.com/xwiki/bin/view/Main/Node-RED/#H3.A0ImportInputFlowforDraginoSensors)) décrit comment utiliser Node-Red pour programmer l'envoie d'une commande par le Serveur ChirpStack voir: [5.1 How to use Node-Red to schedule downlink to ChirpStack LoRaWAN Server?](https://wiki.dragino.com/xwiki/bin/view/Main/Node-RED/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)

ll

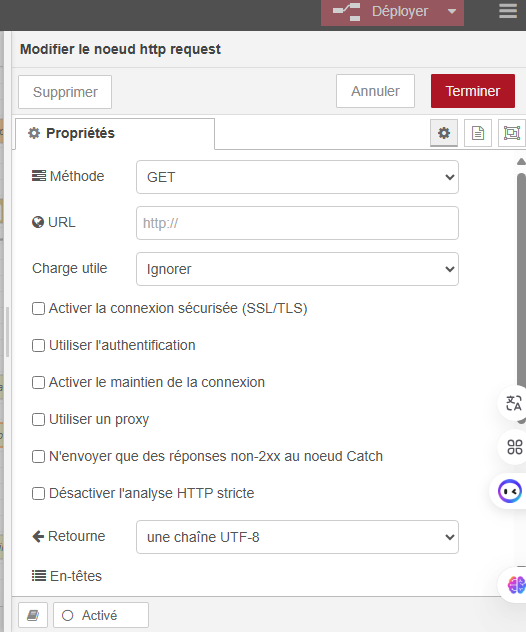
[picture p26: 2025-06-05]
medias/red_node_post_openwindmap.png

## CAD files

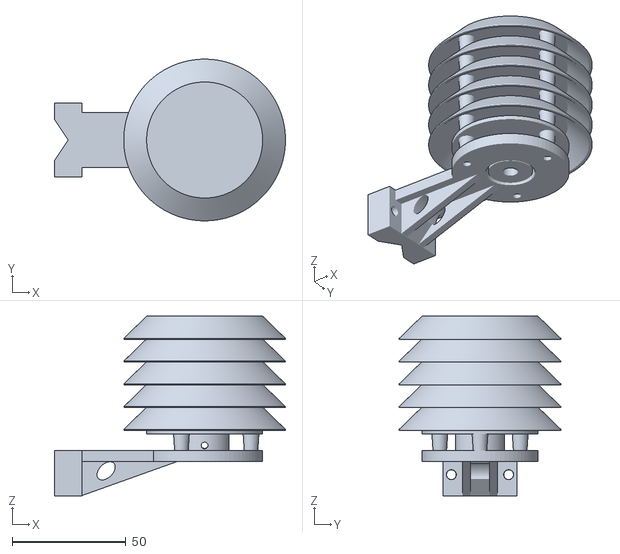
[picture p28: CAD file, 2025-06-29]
medias/Rad_Shd_Vert_mount_complet_V3_60%.stl
101.6 x 71.1 x 79.0

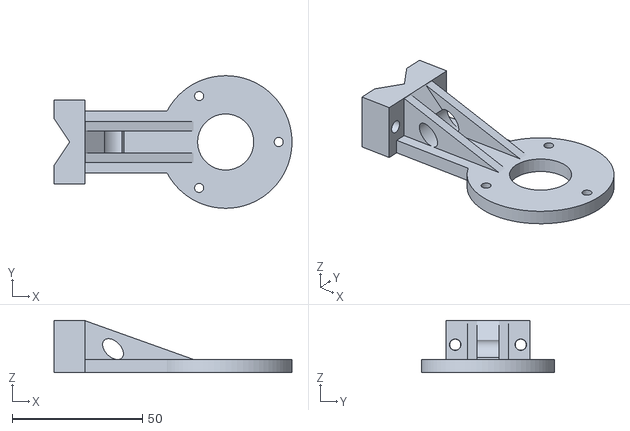
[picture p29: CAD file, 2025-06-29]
medias/Rad_Shd_Vert_mount_60%.stl
91.5 x 51.0 x 20.0

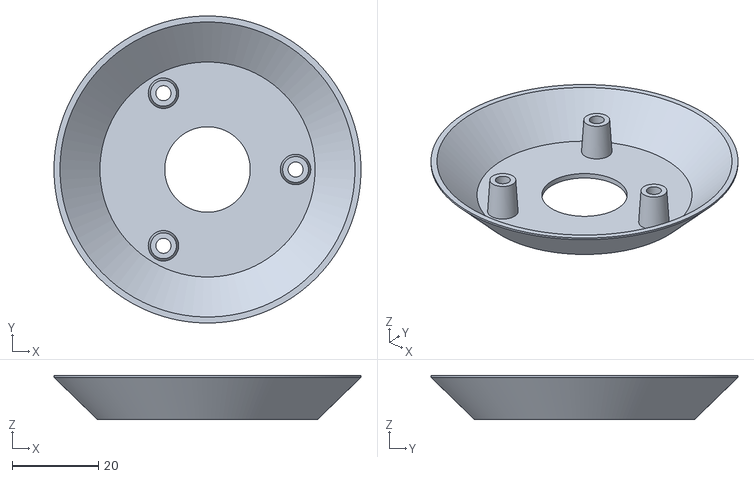
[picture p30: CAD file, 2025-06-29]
medias/Rad_Shd_ailette_60%.stl
71.1 x 71.1 x 10.2

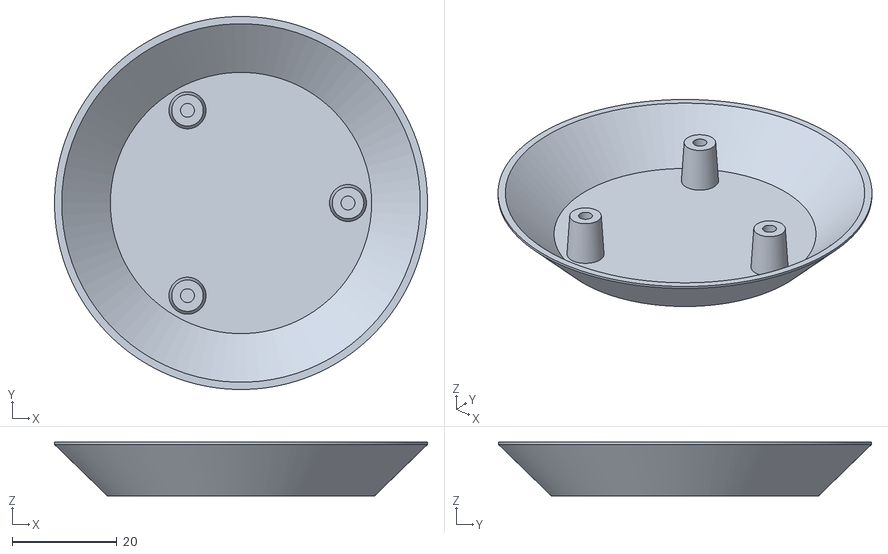
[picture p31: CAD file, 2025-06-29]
medias/Rad_Shd_ailette_superieur_60%.stl
71.1 x 71.1 x 10.2

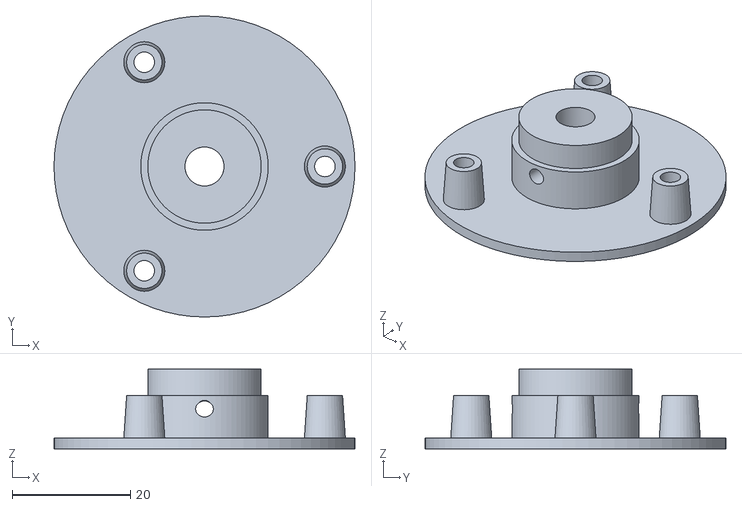
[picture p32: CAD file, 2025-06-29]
medias/Rad_Shd_Porte_sonde_60%.stl
51.0 x 51.0 x 13.5

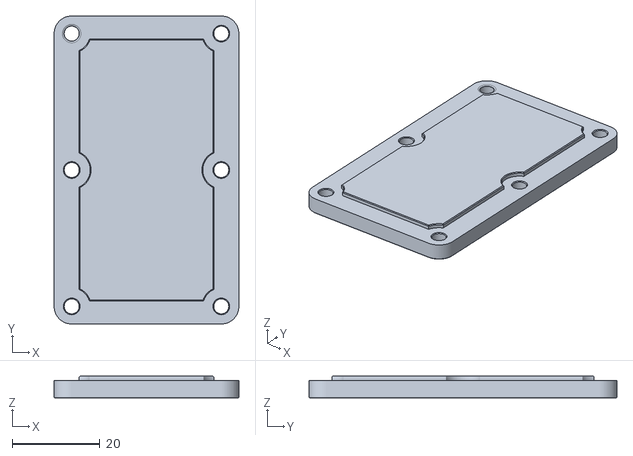
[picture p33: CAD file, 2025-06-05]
medias/boitier connexion haut.stl
42.0 x 70.0 x 5.00

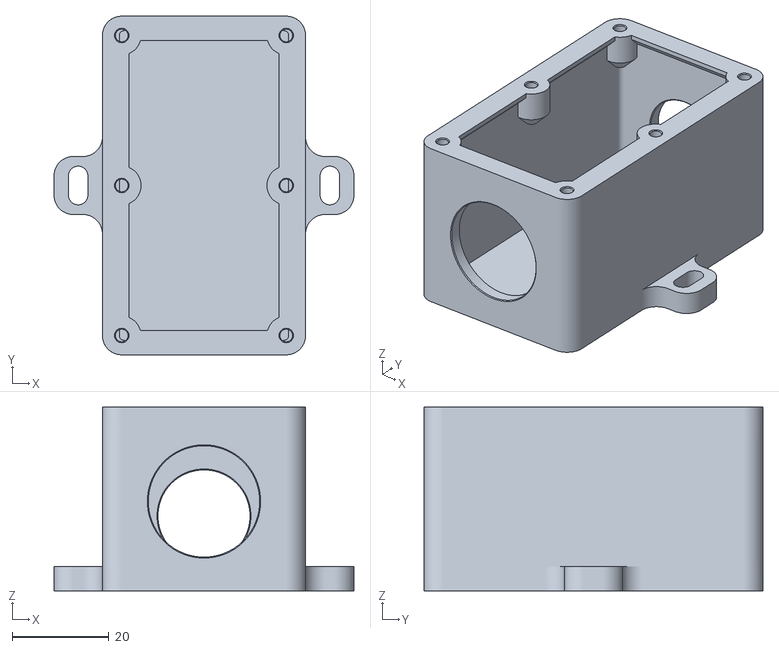
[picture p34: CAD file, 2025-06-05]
medias/boitier connexion bas.stl
62.0 x 70.0 x 38.0

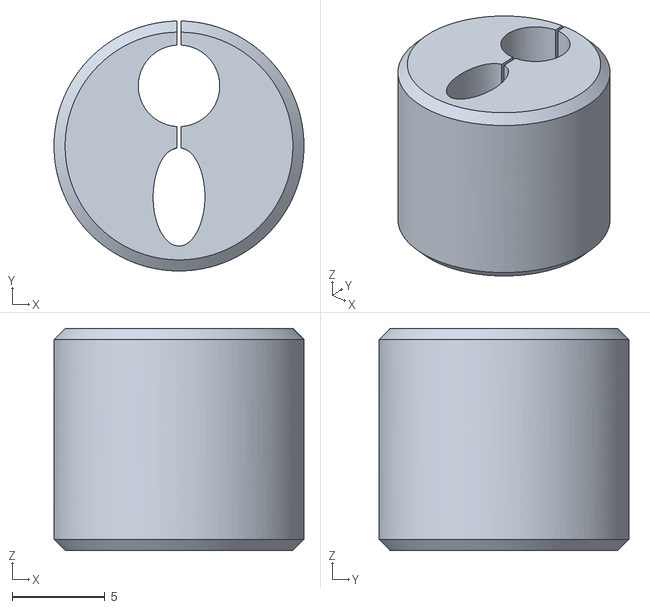
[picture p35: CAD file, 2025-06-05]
medias/bague etanche d13.5_d4mm.stl
13.5 x 13.5 x 12.0

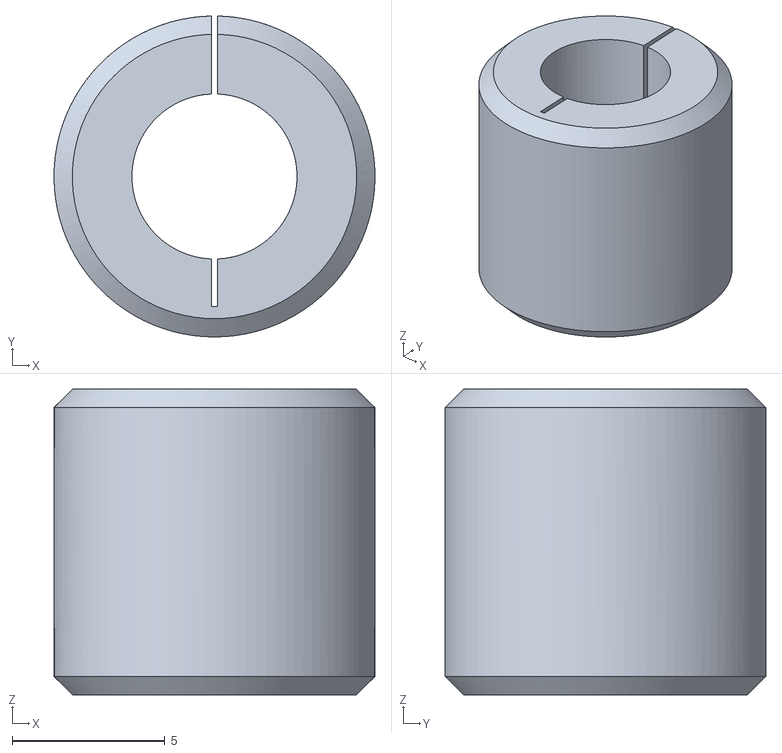
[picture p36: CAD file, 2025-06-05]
medias/bague etanche d10.5_d5mm.stl
10.5 x 10.5 x 10.0

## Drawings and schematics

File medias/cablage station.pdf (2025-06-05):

Boitier de connexion | SN50v3-LB/LS

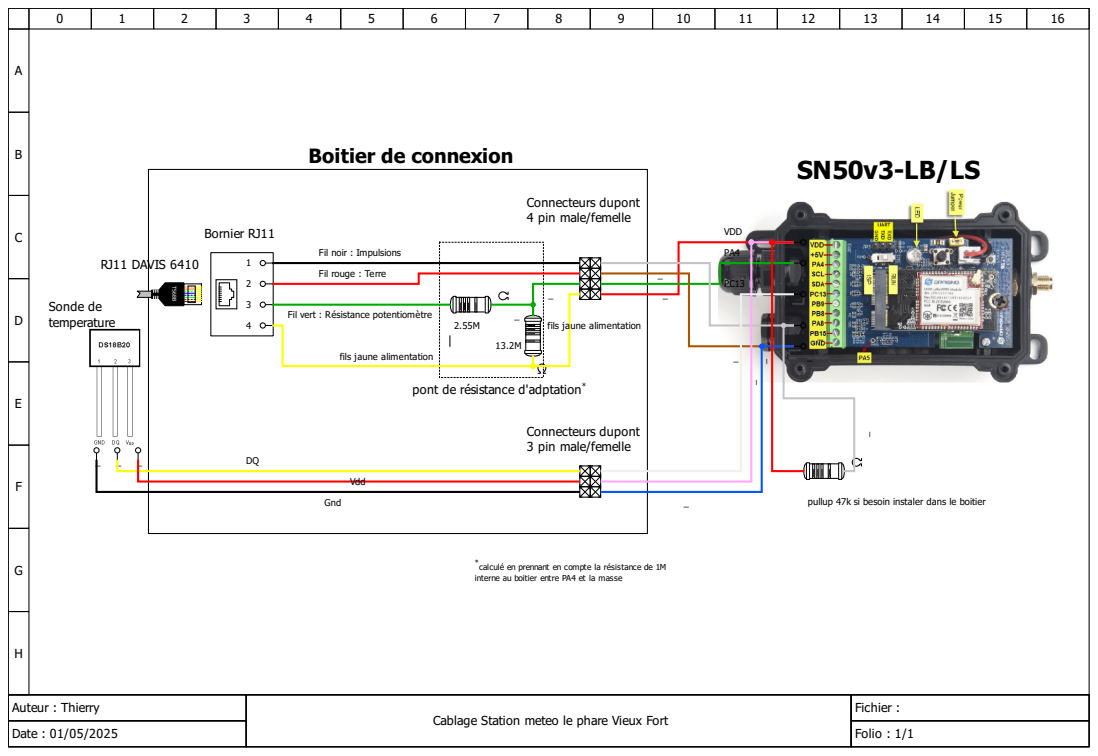
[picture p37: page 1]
Auteur : Thierry; Fichier :; Date : 01/05/2025; Folio : 1/1; RJ11 DAVIS 6410; Bornier RJ11; VDD; Sonde de temperature; Fil vert : Résistance potentiomètre; Gnd; Vdd

Connecteurs dupont
4 pin male/femelle

Fil noir : Impulsions
Fil rouge : Terre

fils jaune alimentation

pont de résistance d'adptation

3 pin male/femelle

pullup 47k si besoin instaler dans le boitier

calculé en prennant en compte la résistance de 1M
interne au boitier entre PA4 et la masse

Cablage Station meteo le phare Vieux Fort

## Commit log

2025-05-02 Update README.md
    j'ai fait quelques ajout dans le texte sur les références et prix plus correction mineur sur la tension du signal girouette
2025-05-02 Update README.md
    mise à jour du schema de résistance
2025-05-02 Fichier STL du boitier de connexion
    [bague etanche d10.5_d5mm.stl, bague etanche d13.5_d4mm.stl, boitier connexion bas.stl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]
2025-06-05 Rename red node insert influx 1.png to red_node_insert_influx_1.png
2025-06-05 Rename red node switch.png to red_node_switch.png
2025-06-07 Update README.md
    ajout de détail sur le boitier de connection
2025-06-07 Update README.md
    mise à jour de la configuration du boitier
2025-06-07 Update README.md
    correction de typo et ajoute de précision sur la calibration
2025-06-07 Update README.md
    mise à jour de la fiche produit de la girouette
2025-06-07 Update README.md
    correction de typo
2025-06-29 Add files via upload
    fichiers STL de l'écran radiatif
    [Rad_Shd_Porte_sonde_60%.stl, Rad_Shd_Vert_mount_60%.stl, Rad_Shd_Vert_mount_complet_V3_60%.stl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]
2026-07-13 Update README.md
    mise à jour des liens obsolete
2026-07-13 Update README.md
    mise à jour de liens obsolete
2026-07-13 Update README.md
    mise à jour de lien obsolète
